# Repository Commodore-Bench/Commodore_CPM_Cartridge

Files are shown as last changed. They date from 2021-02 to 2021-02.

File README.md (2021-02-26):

# Commodore CP/M Cartridge for Commodore C64

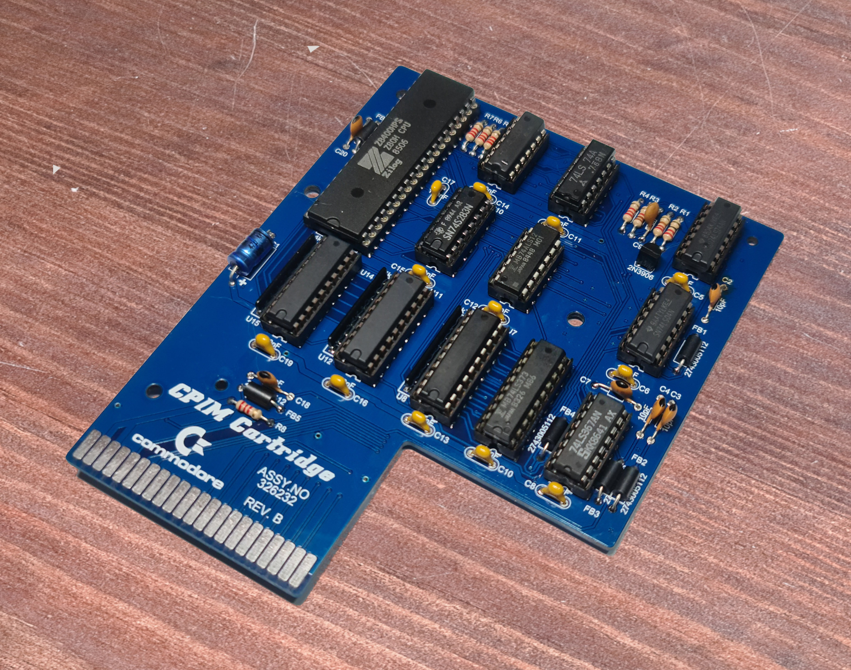
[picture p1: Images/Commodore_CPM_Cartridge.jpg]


This is a replica of the Commodore CP/M cartridge, with which it was possible to use CP/M in version 2.2.

## Introduction

In the course of my other Z80 cartridge project here on GitHub, I had first rebuilt the original Commodore CP/M cartridge for analysis purposes.

I kept as much as possible to the original board and only adapted a few footprints to the current parts supply. The board is identical to the original board in dimensions and drillings, so that it also fits into the case of the Commodore version.

Due to the 1:1 reproduction, this cartridge has of course all the corresponding "problems" in terms of compatibility.

I have the card in both 407er, as well as 469 board to run without problems. The installed VIC apparently played no role.

But the used components on the CP/M board do play a role.

Normally "LS" types should be used, thus 74LS00, 75LS04, etc..

But it also helps to try "ALS" and "HCT" types here and there. Unfortunately, I cannot give an ideal recipe here. Only the hint that in the 407 board everything in "LS" is without problems.

## BOM

As mentioned earlier, this parts list should work exactly the same on the older boards. If there are problems, you can try to exchange single parts against "ALS" or "HCT" types. A version with 4MHZ is also sufficient for the CPU.

Please then not all at once, but always first only individually.

| # | Manufacturer | Part Number | Case | Description | Quantity |
| ---- | --- | --- | --- | --- | --- |
| 1 | Central Semiconductor | 2N3906 | TO-92  | Bipolar  Transistor PNP Amplifier/Switch 40V 200mA 3-Pin TO-92 Through Hole Box | 1 |
| 2 | Fair-Rite | 2743005112 | Axial  | Ferrite  Beads Axial 91Ohm 100MHz T/R | 6 |
| 3 | Vishay BCcomponents | A100J15C0GF5TAA  | Axial  | Cap Ceramic  10pF 50V C0G 5% Axial 125C T/R | 6 |
| 4 | Vishay  BCcomponents  | A470J15C0GF5TAA  | Axial  | Cap  Ceramic 47pF 50V C0G 5% Axial 125C T/R | 1 |
| 5 | KEMET | C330C104J5R5TA | Dipped | Cap Ceramic  0.1uF 50V X7R 5% Radial 5.08mm 125C Bulk | 12 |
| 6 | Yageo | CFR-25JB-52-1K2  | Axial  | RES  1.2K OHM 1/4W 5% AXIAL | 1 |
| 7 | Yageo | CFR-25JB-52-2K2  | Axial  | RES 2.2K OHM  1/4W 5% AXIAL | 5 |
| 8 | Yageo | CFR-25JB-52-22R  | Axial  | RES  22 OHM 1/4W 5% AXIAL | 1 |
| 9 | Yageo | CFR-25JB-52-220R | Axial  | RES 220 OHM  1/4W 5% AXIAL | 1 |
| 10 | Vishay  Dale | CSC09A014K70GPA  | SIP | Resistor  Networks & Arrays 9pin 4.7Kohms 2% Bussed | 3 |
| 11 | Vishay | MAL203036479E3 | Axial  | Cap Aluminum  47uF 25V -10% to 50% (6 X 10mm) Axial 4.8 Ohm 100mA 3000 hr 85C Taped in Box | 1 |
| 12 | Texas  Instruments | SN74LS00N | PDIP | IC,  74LS, 74LS00, DIP14, 5.25V | 1 |
| 13 | Texas Instruments | SN74LS04N | PDIP | IC HEX INVERTER  14-DIP | 1 |
| 14 | Texas  Instruments | SN74LS12N | PDIP | Logic  Gates Triple 3-input Positive-NAND gates with open collector outputs 14-PDIP  0 to 70 | 1 |
| 15 | Texas Instruments | SN74LS74AN | PDIP | TEXAS  INSTRUMENTS  SN74LS74AN  Flip-Flop, with Set and Reset,  Complementary Output, Differential, Positive Edge, D, 13 ns, 33 MHz | 2 |
| 16 | Texas  Instruments | SN74LS245N | PDIP | IC  TXRX NON-INVERT 5.25V 20DIP | 3 |
| 17 | ON Semiconductor | SN74LS283N | PDIP | Binary Full  Adder Single 4-Bit 16-Pin PDIP Box | 1 |
| 18 | ON  Semiconductor | SN74LS367AN | PDIP | I.C.  SN74LS 367 AN | 1 |
| 19 | Texas Instruments | SN74LS373N | PDIP | Latch  Transparent 3-ST 8-CH D-Type 20-Pin PDIP Tube | 1 |
| 20 | Ixys  Zilog | Z84C0008PEG | DIP | IC  MPU Z80 8MHZ 40DIP | 1 |

------

## PCB

The PCB can either be ordered directly from [PCBWay](https://www.pcbway.com/project/shareproject/Commodore_CP_M_Cartridge.html), or you can create it yourself from the Gerber files available here.

PCBWay (https://www.pcbway.com/project/shareproject/Commodore_CP_M_Cartridge.html)

If you liked my project, I would be very happy about a small coffee donation.



# License

The contents of this repository, with the exception of the Docs and Software directories, are released under the following license:

- the "Creative Commons Attribution-NonCommercial-ShareAlike 4.0 International License" (CC BY-NC-SA 4.0) full text of this license is included in the [LICENSE.CC-NC-BY-SA-4.0](https://github.com/DL2DW/Z80-Card_for_Commodore_C64/blob/main/LICENSE.CC-NC-BY-SA) file and a copy can also be found at https://creativecommons.org/licenses/by-nc-sa/4.0/

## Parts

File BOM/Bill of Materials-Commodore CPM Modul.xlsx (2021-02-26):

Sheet: Part List Report
 | Component list |  |  | Bill of Materials for Project [Commodore CPM Modul.PrjPcb] (PCB Document : Commodore CPM Modul.PcbDoc)
 | Source Data From: | Commodore CPM Modul.PrjPcb |  |  | Contact: |  |  |  | Generated by:
 | Project: | Commodore CPM Modul.PrjPcb |  |  | <Parameter ClientCompanyName not found>
 | Variant: | None |  |  | <Parameter ClientContactName not found>
 |  |  |  |  | <Parameter ClientContactEmail not found>
 | Report Date: | 14.02.2021 | 10:00 |  | <Parameter ClientWebsite not found>
 | Print Date: | 2021-02-14 | 10:00:25
# | #Column Name Error:' Category | Manufacturer 1 | Manufacturer Part Number 1 | Case/Package | Description | Quantity | Supplier 1 | Supplier Part Number 1 | Supplier Order Qty 1 | Supplier Stock 1 | Supplier Unit Price 1 | Supplier Subtotal 1 | Supplier Currency 1
1 |  | Central Semiconductor | 2N3906 | TO-92 | Bipolar Transistor PNP Amplifier/Switch 40V 200mA 3-Pin TO-92 Through Hole Box | 1 | Digi-Key | 1514-2N3906PBFREE-ND | 1 | 4539 | 0.44 | 0.44 | USD
2 |  | Fair-Rite | 2743005112 | Axial | Ferrite Beads Axial 91Ohm 100MHz T/R | 6 | Digi-Key | 1934-1416-1-ND | 6 | 43761 | 0.16 | 0.96 | USD
3 |  | Vishay BCcomponents | A100J15C0GF5TAA | Axial | Cap Ceramic 10pF 50V C0G 5% Axial 125C T/R | 6 | Digi-Key | A100J15C0GF5TAA-ND |  | 0 |  |  | USD
4 |  | Vishay BCcomponents | A470J15C0GF5TAA | Axial | Cap Ceramic 47pF 50V C0G 5% Axial 125C T/R | 1 | Digi-Key | A470J15C0GF5TAA-ND |  | 0 |  |  | USD
5 |  | KEMET | C330C104J5R5TA | Dipped | Cap Ceramic 0.1uF 50V X7R 5% Radial 5.08mm 125C Bulk | 12 | Digi-Key | 399-C330C104J5R5TA-ND |  | 0 |  |  | USD
6 |  | Yageo | CFR-25JB-52-1K2 | Axial | RES 1.2K OHM 1/4W 5% AXIAL | 1 | Digi-Key | 1.2KQBK-ND | 1 | 44543 | 0.10 | 0.10 | USD
7 |  | Yageo | CFR-25JB-52-2K2 | Axial | RES 2.2K OHM 1/4W 5% AXIAL | 5 | Digi-Key | 2.2KQBK-ND | 5 | 39446 | 0.10 | 0.50 | USD
8 |  | Yageo | CFR-25JB-52-22R | Axial | RES 22 OHM 1/4W 5% AXIAL | 1 | Digi-Key | 22QBK-ND | 1 | 40888 | 0.10 | 0.10 | USD
9 |  | Yageo | CFR-25JB-52-220R | Axial | RES 220 OHM 1/4W 5% AXIAL | 1 | Digi-Key | 220QBK-ND | 1 | 30267 | 0.10 | 0.10 | USD
10 |  | Vishay Dale | CSC09A014K70GPA | SIP | Resistor Networks & Arrays 9pin 4.7Kohms 2% Bussed | 3 | Mouser | 71-CSC09A01-4.7K | 3 | 1746 | 2.61 | 7.83 | USD
11 |  | Vishay | MAL203036479E3 | Axial | Cap Aluminum 47uF 25V -10% to 50% (6 X 10mm) Axial 4.8 Ohm 100mA 3000 hr 85C Taped in Box | 1 | Element14 | 1165421 |  | 5065
12 |  | Texas Instruments | SN74LS00N | PDIP | IC, 74LS, 74LS00, DIP14, 5.25V | 1 | Element14 | 1106069 |  | 0
13 |  | Texas Instruments | SN74LS04N | PDIP | IC HEX INVERTER 14-DIP | 1 | Element14 | 1106072 |  | 9170
14 |  | Texas Instruments | SN74LS12N | PDIP | Logic Gates Triple 3-input Positive-NAND gates with open collector outputs 14-PDIP 0 to 70 | 1 |  |  |  | 0
15 |  | Texas Instruments | SN74LS74AN | PDIP | TEXAS INSTRUMENTS SN74LS74AN Flip-Flop, with Set and Reset, Complementary Output, Differential, Positive Edge, D, 13 ns, 33 MHz | 2 | Element14 | 1105907 |  | 0
16 |  | Texas Instruments | SN74LS245N | PDIP | IC TXRX NON-INVERT 5.25V 20DIP | 3 | Element14 | 1106085 |  | 1528
17 |  | ON Semiconductor | SN74LS283N | PDIP | Binary Full Adder Single 4-Bit 16-Pin PDIP Box | 1 |  |  |  | 0
18 |  | ON Semiconductor | SN74LS367AN | PDIP | I.C. SN74LS 367 AN | 1 |  |  |  | 0
19 |  | Texas Instruments | SN74LS373N | PDIP | Latch Transparent 3-ST 8-CH D-Type 20-Pin PDIP Tube | 1 | Element14 | 1470892 |  | 0
20 |  | Ixys Zilog | Z84C0008PEG | DIP | IC MPU Z80 8MHZ 40DIP | 1 | Element14 | 1081890 |  | 0
 |  |  |  |  |  | 50 |  |  | 18 |  |  | 10.03
Approved |  |  |  | Notes
 |  |  |  |  |  | 1 | pcs: | Total |  | 10.03 |  | USD
 |  |  |  |  |  |  |  | Price for 1pcs |  | 10.03 |  | USD

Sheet: Project Information
Project Full Path | D:\Elektronik\Altium\Projects\Commodore CPM Modul\Commodore CPM Modul.PrjPcb
Project Filename | Commodore CPM Modul.PrjPcb
Variant Name | None
Data-Source Filename | Commodore CPM Modul.PrjPcb
Data-Source Full Path | D:\Elektronik\Altium\Projects\Commodore CPM Modul\Commodore CPM Modul.PrjPcb
Title | Bill of Materials for Project [Commodore CPM Modul.PrjPcb] (PCB Document : Commodore CPM Modul.PcbDoc)
Total Quantity | 50
Report Time | 10:00
Report Date | 14.02.2021
Report Date & Tine | 14.02.2021 10:00
Output Name | Bill of Materials
Output Type | BOM_PartType
Output Generator Name | BOM
Output Generator Description | Bill of Materials

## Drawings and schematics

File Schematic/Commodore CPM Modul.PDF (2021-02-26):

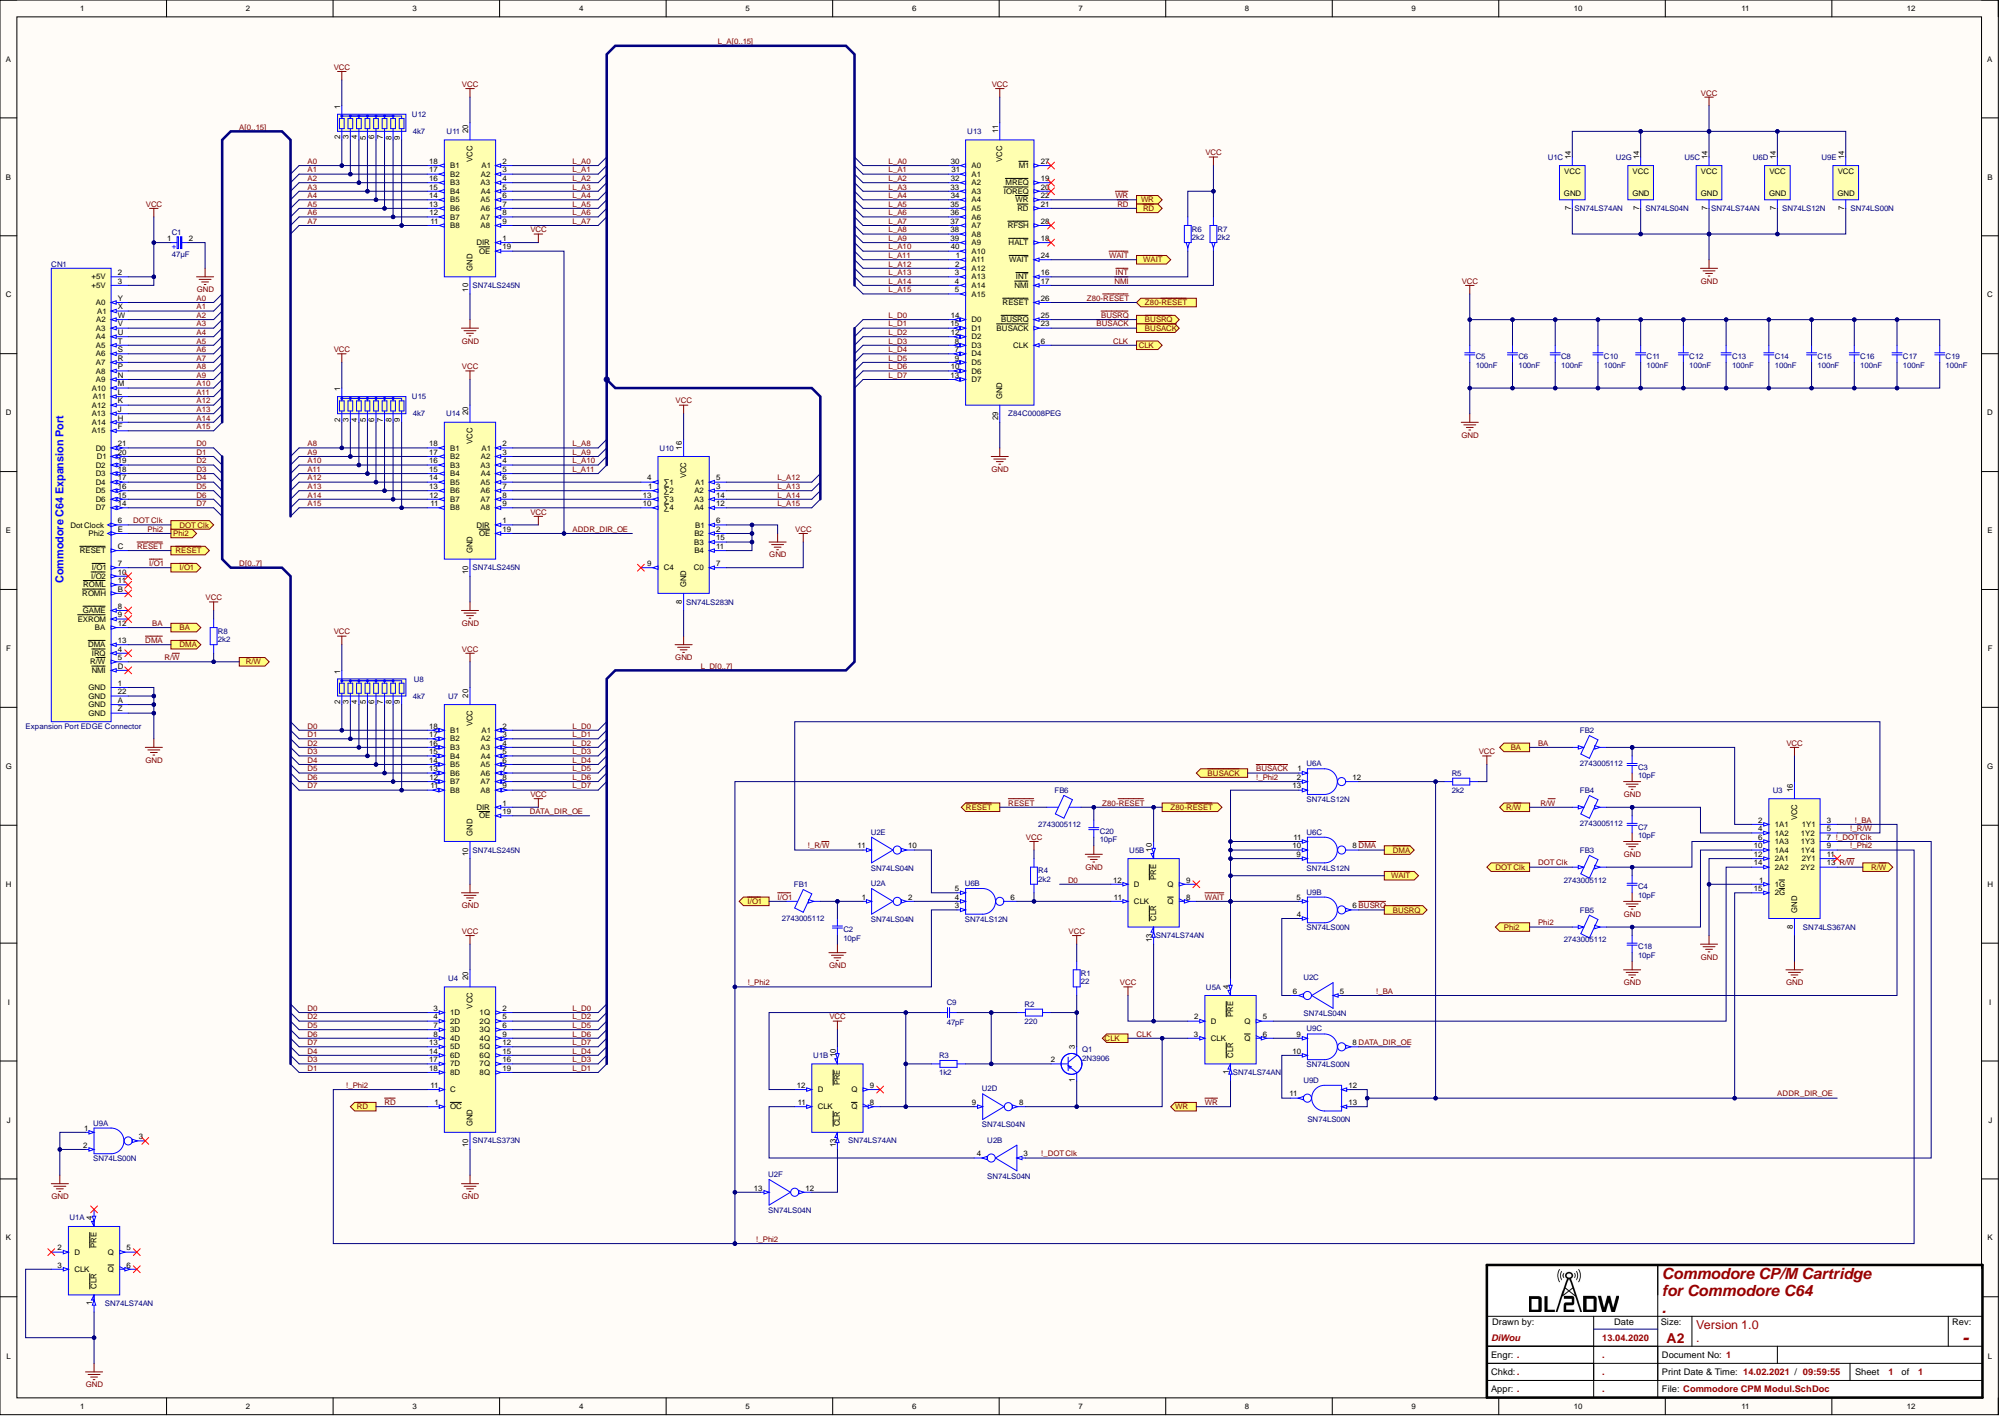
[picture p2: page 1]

1 | VC

C 7 | 4 | 1Y2 1A2 1A3 | 5 !_R /W
10p F | | | 7 !_DOT Clk

U 6 B | | | | | | 9 | | DOT Clk | GN | D | 2Y1 2Y2 1G | 1 2A1 12 13 2A2 14

10 | | | 8 D M | A D M A | F B 3 | 1Y4 | 9 1A4 10 !_Phi 2

Engr : . | .. | Document No: 1

Chkd: . | | P rint Date & Time: 14.02.202 1 / 09:59: 5 5 | Sheet 1 of 1

Appr : . | . | Co m m o d o re CP M M o d ul.SchDo c
